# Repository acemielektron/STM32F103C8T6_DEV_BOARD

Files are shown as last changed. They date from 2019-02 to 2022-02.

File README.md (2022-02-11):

# STM32F103C8T6_DEV_BOARD

Single sided DIY PCB for STM32F103C8T6

There are many pcb designs for stm32f103C8T6 what makes this design special is:
- it's single sided
- minimum number of bridges at top side (only one bridge)
so it's very diy friendly (I think).

Here is photos of earlier version:
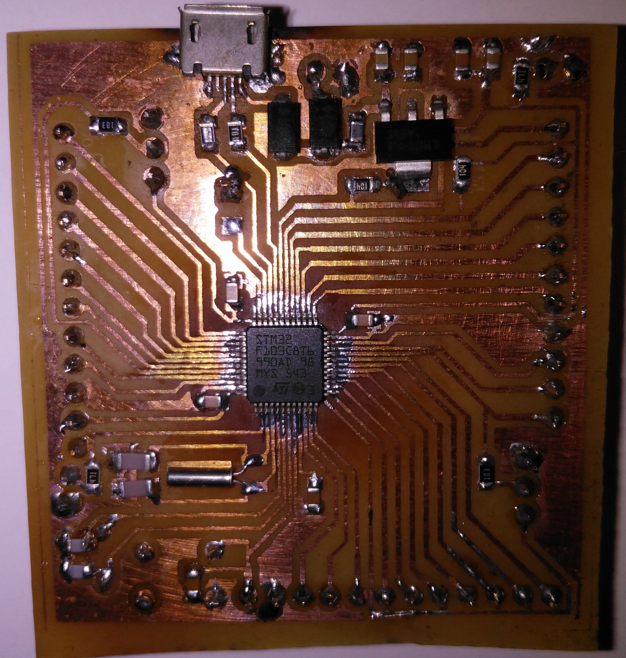
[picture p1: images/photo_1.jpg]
Bottom side</img>
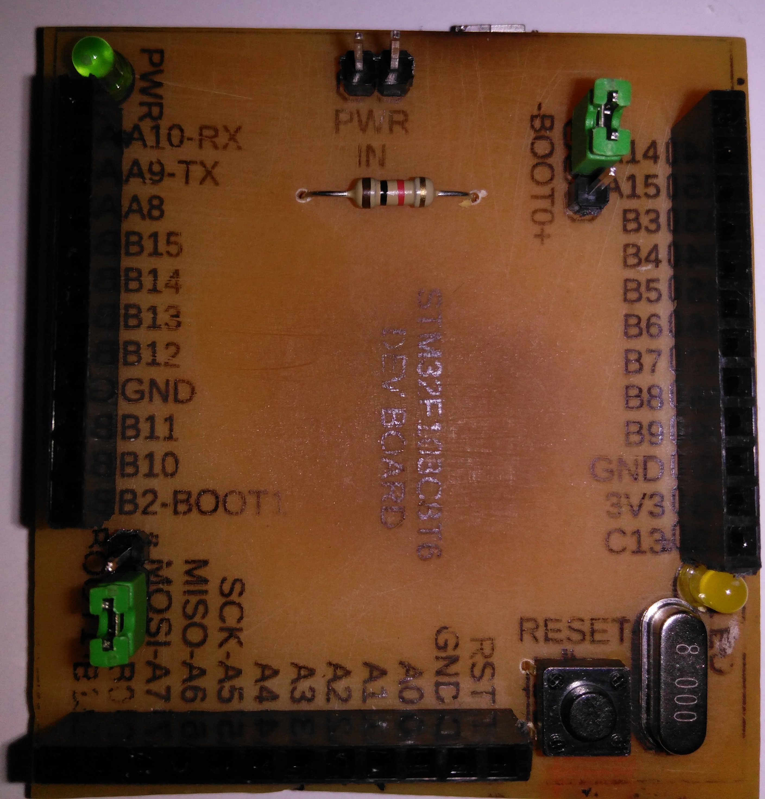
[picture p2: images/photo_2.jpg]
Top side</img>

And here images of pcb and schematic
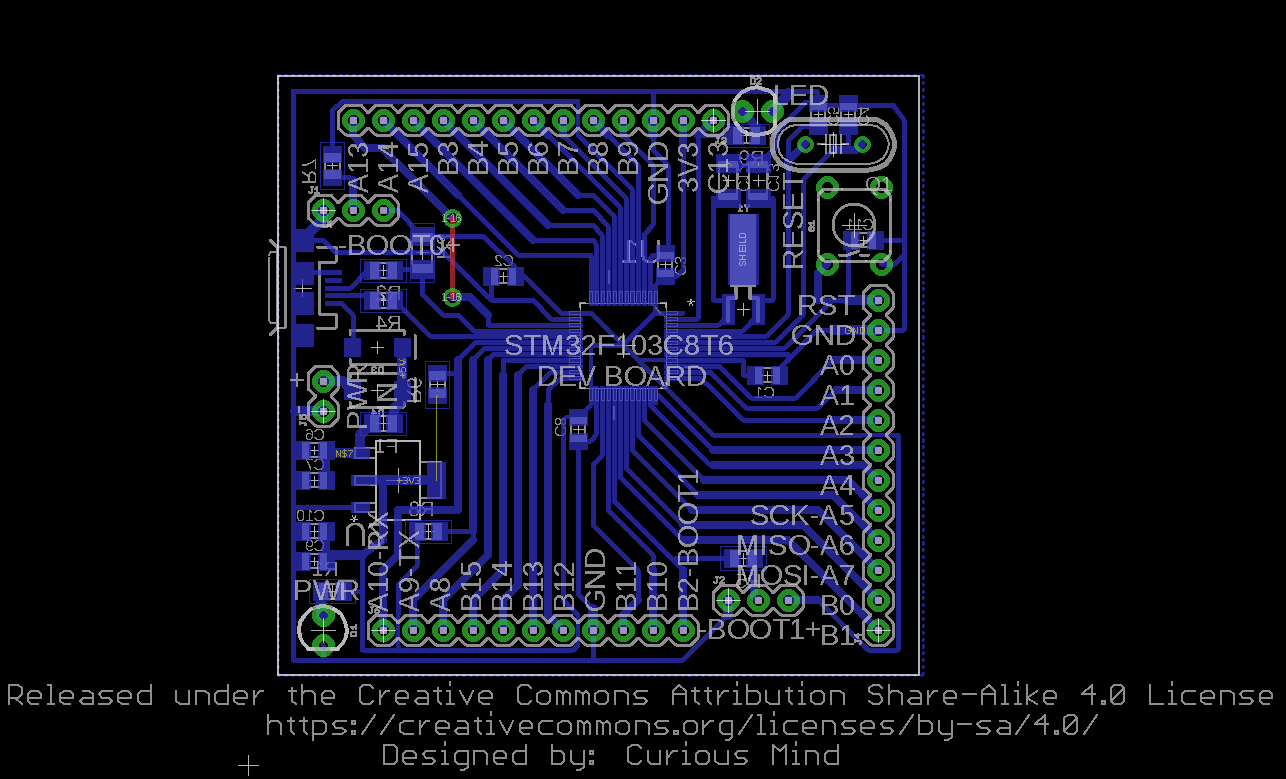
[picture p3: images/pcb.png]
pcb</img>
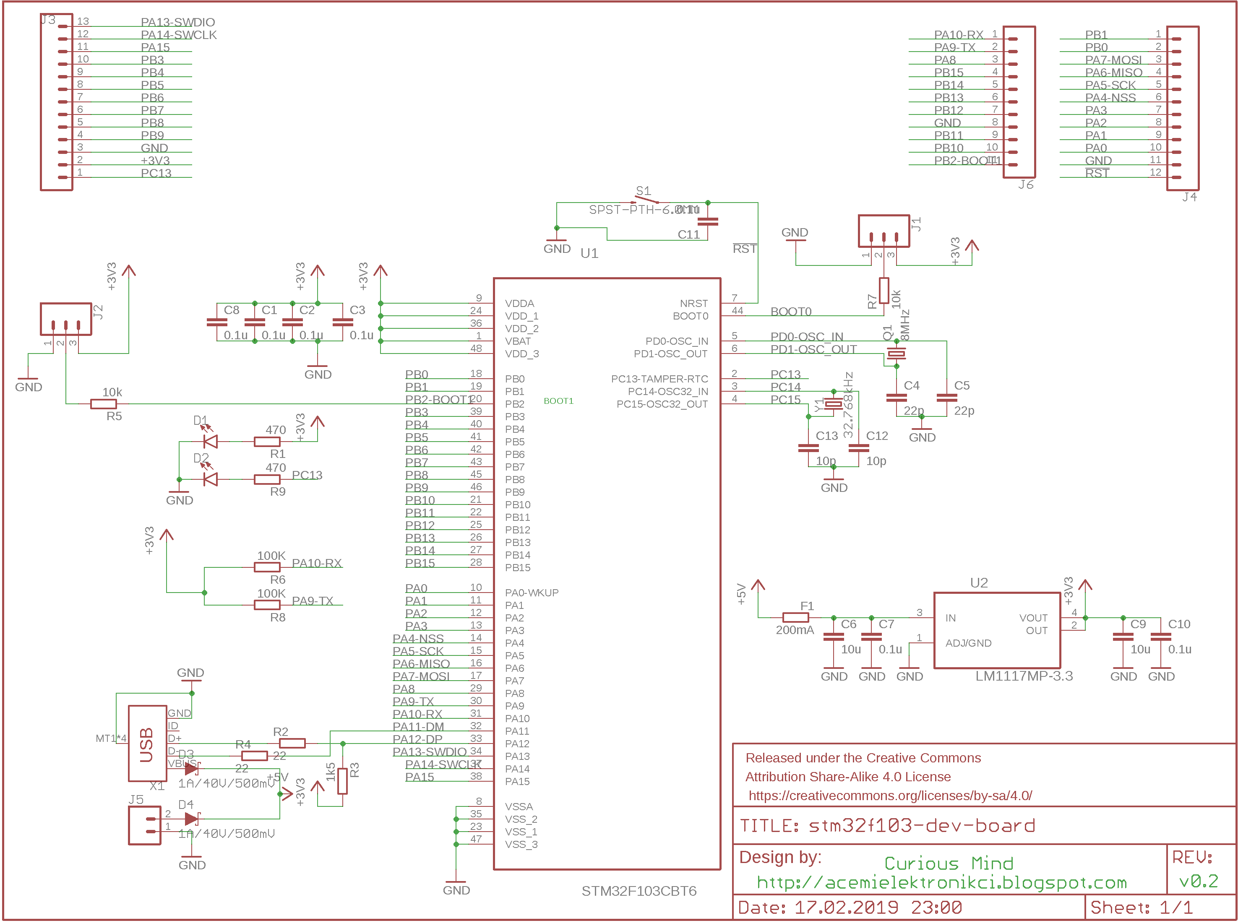
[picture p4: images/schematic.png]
schematic</img>



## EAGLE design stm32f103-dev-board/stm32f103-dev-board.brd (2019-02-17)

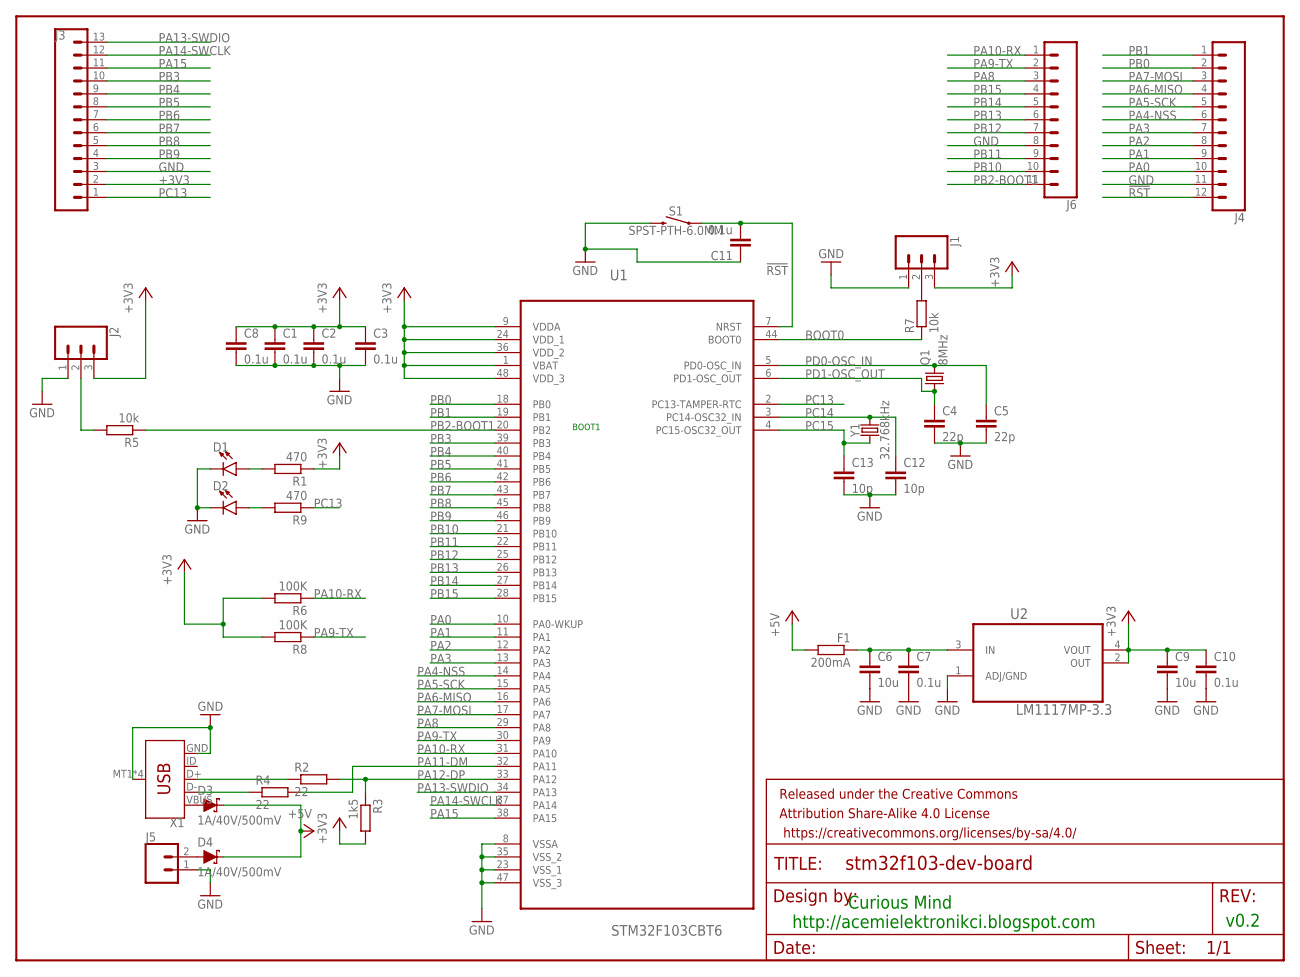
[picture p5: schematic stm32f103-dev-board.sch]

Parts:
C1, C2, C3, C7, C8, C10, C11: 0.1u; C0805K
C4, C5: 22p; C0805K
C6, C9: 10u; C0805K
C12, C13: 10p; C1206K
D1, D2: LED3MM; LED_3MM
D3, D4: 1A/40V/500mV; SMA-DIODE
F1: 200mA; R0805
FRAME1: FRAME-LETTER; CREATIVE_COMMONS
J1, J2: CONN_03; 1X03
J3: CONN_13; 1X13
J4: CONN_12; 1X12
J5: CONN_02; 1X02
J6: CONN_11; 1X11
Q1: 8MHz; HC49/S
R1, R9: 470; R0805
R2, R4: 22; R0805
R3: 1k5; R1206
R5, R7: 10k; R0805
R6, R8: 100K; R0805
S1: SPST-PTH-6.0MM; TACTILE_SWITCH_PTH_6.0MM
U1: STM32F103CBT6; QFP50P900X900X160-48N
U2: LM1117MP-3.3; SOT230P696X180-4N
X1: USB_MICRO-B_SMT; USB-MICROB
Y1: 32.768kHz; CRYSTAL-SMD-2X6-CYL

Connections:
!RST: C11.2, J4.12, S1.1, U1.7 (NRST)
+3V3: C1.1, C2.1, C3.1, C8.1, C9.1, C10.1, J1.3, J2.3, J3.2, R1.1, R3.2, R6.2, R8.2, U1.1 (VBAT), U1.9 (VDDA), U1.24 (VDD_1), U1.36 (VDD_2), U1.48 (VDD_3), U2.2 (OUT), U2.4 (VOUT)
+5V: D3.C, D4.C, F1.2
BOOT0: R7.1, U1.44 (BOOT0)
GND: C1.2, C2.2, C3.2, C4.2, C5.2, C6.2, C7.2, C8.2, C9.2, C10.2, C11.1, C12.2, C13.2, D1.K (C), D2.K (C), J1.1, J2.1, J3.3, J4.11, J5.1, J6.8, S1.3 (2), U1.8 (VSSA), U1.23 (VSS_1), U1.35 (VSS_2), U1.47 (VSS_3), U2.1 (ADJ/GND), X1.GND, X1.MT1 (SHIELD), X1.MT2 (SHIELD), X1.P$1 (SHIELD), X1.P$2 (SHIELD)
unnamed: D3.A, X1.VBUS
unnamed: D2.A, R9.2
unnamed: D1.A, R1.2
unnamed: J1.2, R7.2
unnamed: D4.A, J5.2
unnamed: C6.1, C7.1, F1.1, U2.3 (IN)
unnamed: R4.1, X1.D-
unnamed: R2.1, X1.D+
unnamed: J2.2, R5.2
PA0: J4.10, U1.10 (PA0-WKUP)
PA1: J4.9, U1.11 (PA1)
PA2: J4.8, U1.12 (PA2)
PA3: J4.7, U1.13 (PA3)
PA4-NSS: J4.6, U1.14 (PA4)
PA5-SCK: J4.5, U1.15 (PA5)
PA6-MISO: J4.4, U1.16 (PA6)
PA7-MOSI: J4.3, U1.17 (PA7)
PA8: J6.3, U1.29 (PA8)
PA9-TX: J6.2, R8.1, U1.30 (PA9)
PA10-RX: J6.1, R6.1, U1.31 (PA10)
PA11-DM: R4.2, U1.32 (PA11)
PA12-DP: R2.2, R3.1, U1.33 (PA12)
PA13-SWDIO: J3.13, U1.34 (PA13)
PA14-SWCLK: J3.12, U1.37 (PA14)
PA15: J3.11, U1.38 (PA15)
PB0: J4.2, U1.18 (PB0)
PB1: J4.1, U1.19 (PB1)
PB2-BOOT1: J6.11, R5.1, U1.20 (PB2)
PB3: J3.10, U1.39 (PB3)
PB4: J3.9, U1.40 (PB4)
PB5: J3.8, U1.41 (PB5)
PB6: J3.7, U1.42 (PB6)
PB7: J3.6, U1.43 (PB7)
PB8: J3.5, U1.45 (PB8)
PB9: J3.4, U1.46 (PB9)
PB10: J6.10, U1.21 (PB10)
PB11: J6.9, U1.22 (PB11)
PB12: J6.7, U1.25 (PB12)
PB13: J6.6, U1.26 (PB13)
PB14: J6.5, U1.27 (PB14)
PB15: J6.4, U1.28 (PB15)
PC13: J3.1, R9.1, U1.2 (PC13-TAMPER-RTC)
PC14: C12.1, U1.3 (PC14-OSC32_IN), Y1.X2 (2)
PC15: C13.1, U1.4 (PC15-OSC32_OUT), Y1.X1 (1)
PD0-OSC_IN: C5.1, Q1.2, U1.5 (PD0-OSC_IN)
PD1-OSC_OUT: C4.1, Q1.1, U1.6 (PD1-OSC_OUT)

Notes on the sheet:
BOOT1
Curious Mind http://acemielektronikci.blogspot.com
v0.2

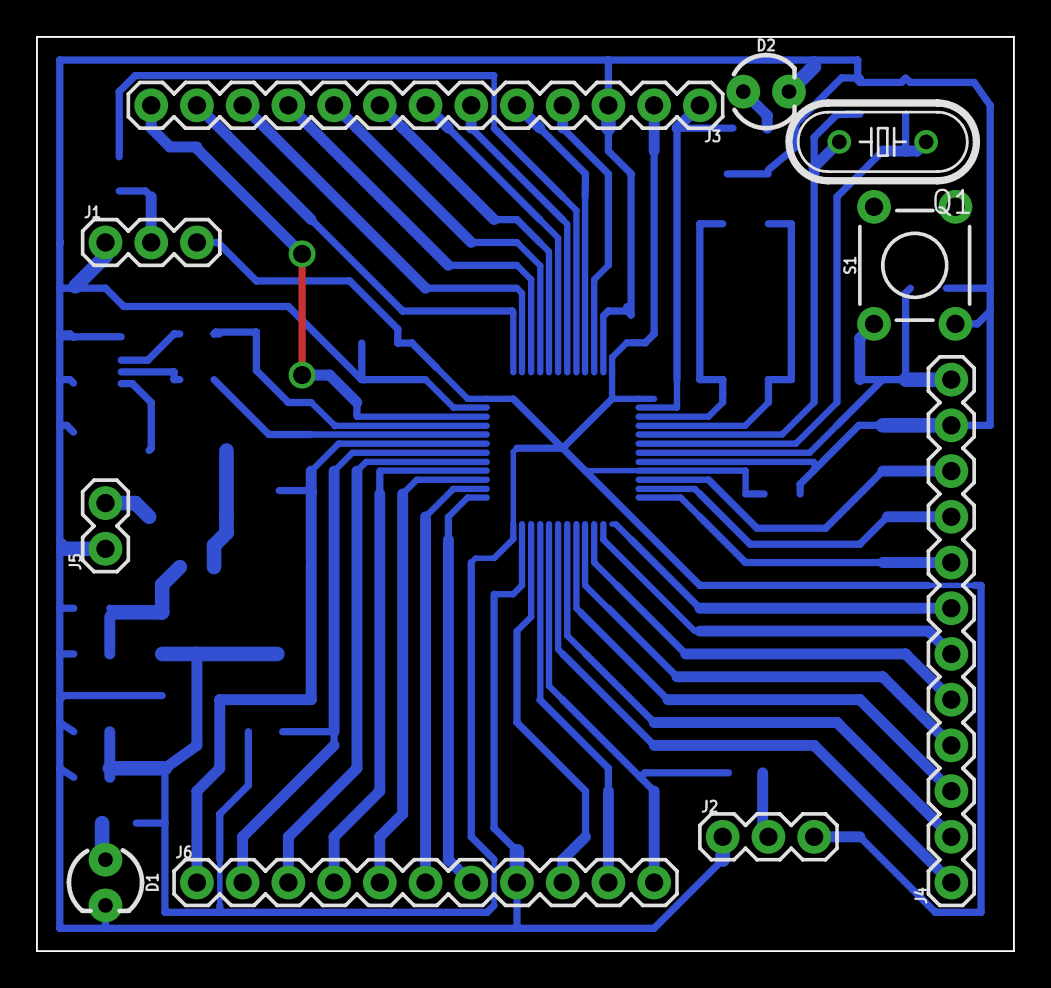
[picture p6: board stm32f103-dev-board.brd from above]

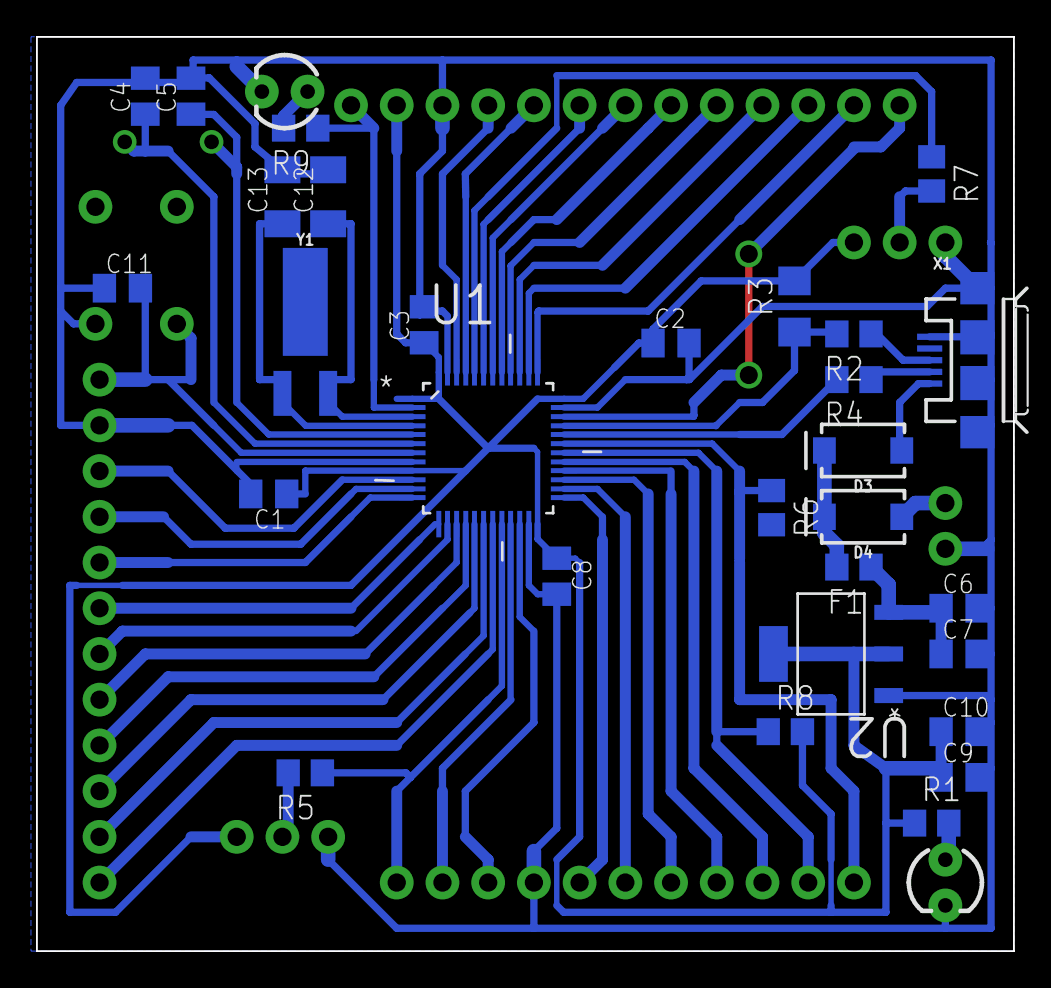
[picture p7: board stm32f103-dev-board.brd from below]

Board: 2 copper layers, 54.3 x 50.8 mm, 40 parts (29 on the bottom side), 51 nets.

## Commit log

2019-02-14 stm32f103c8t6 dev board
    Eagle files
    [stm32f103-dev-board.brd, stm32f103-dev-board.sch]
2019-02-15 v0.2
    added led on PC13
    added power led
    added external power in
    [stm32f103-dev-board.brd, stm32f103-dev-board.sch]
2019-02-17 corrected usb pullup
    corrected usb pullup
    routed swdio (PA13)
    [stm32f103-dev-board.brd, stm32f103-dev-board.sch]
2019-02-17 v0.35 optimization
    [stm32f103-dev-board.brd]
2019-02-18 v0.15
    My first stm32f1 diy board
    Works with arduino ide using "generic_boot20_pc13.bin"
2022-02-11 Put eagle files in folder
    Put eagle files in stm32f103-dev-board folder
    [stm32f103-dev-board.brd, stm32f103-dev-board.sch]

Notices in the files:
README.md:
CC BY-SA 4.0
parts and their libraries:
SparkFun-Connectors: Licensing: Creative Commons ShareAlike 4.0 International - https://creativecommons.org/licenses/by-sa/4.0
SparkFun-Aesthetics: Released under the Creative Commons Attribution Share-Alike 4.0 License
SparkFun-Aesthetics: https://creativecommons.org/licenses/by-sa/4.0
